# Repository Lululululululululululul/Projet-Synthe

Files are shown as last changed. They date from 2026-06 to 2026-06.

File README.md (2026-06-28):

# MONOSTATION — Firmware

Mini-synthétiseur monophonique numérique à synthèse soustractive.
Projet pluridisciplinaire ISEN2 (2025/2026) — groupe **Synthé**.

**Plateforme :** Teensy 4.1 + Teensy Audio Adapter Board Rev D (codec SGTL5000).

## Membres du groupe

- **Mathieu Gattone** — chef de projet
- **Louis Laurent** — développeur (logiciel / DSP)
- **Doryan Le Coadou** — conception mécanique / CAO, responsable Fablab
- **Lucas Desfougeres** — conception électronique, responsable Fablab

Encadrant : Amaury Auguste — Promotion ISEN2, année 2025/2026.

## Démonstration vidéo

▶️ https://youtu.be/DSE_qQ8myZg

---

## Chaîne de traitement du son

```
OSC1 ┐
     ├─► Mixer ─► Filtre passe-bas résonant ─► Enveloppe ADSR ─► Sortie I²S
OSC2 ┘            (State Variable)
```

Deux oscillateurs (le second désaccordable), un mélangeur, un filtre passe-bas
résonant piloté par deux potentiomètres (coupure + résonance), une enveloppe
ADSR, puis la sortie audio I²S vers le codec.

---

## Organisation du code

Le firmware est découpé en **modules**, suivant la séparation
*interface → logique → traitement du signal* présentée dans le rapport. Chaque
module expose son état et ses fonctions dans un en-tête `.h`, et les implémente
dans le `.cpp` correspondant. Le fichier **commun** `config.h` regroupe tout ce
qui est partagé (brochage, constantes, structures).

| Fichier | Rôle |
|---|---|
| `MONOSTATION.ino` | Point d'entrée : `setup()` et `loop()`. Ne fait qu'orchestrer les modules. |
| `config.h` | **En-tête commun** : brochage Teensy, constantes de réglage, structures `Preset` / `SeqEvent` / `Track`. Que des `#define`, `constexpr` et types — aucune variable d'état. |
| `audio_engine.h` / `.cpp` | **Le son** : chaîne audio Teensy, voix monophonique (pile de notes, priorité à la dernière note), note → fréquence + octave, presets, lecture des potentiomètres vers le filtre. |
| `menu.h` / `.cpp` | **Menu + encodeur** : lecture de l'encodeur rotatif (rotation + clic), machine à états du menu, édition des paramètres (qui délègue le travail sonore au moteur audio). |
| `display.h` / `.cpp` | **Affichage OLED** : barre d'état, menu déroulant et sous-menus. Ne fait que *lire* l'état des autres modules. |
| `sequencer.h` / `.cpp` | **Séquenceur** : enregistrement et relecture de courtes pistes (note on/off horodatés). |

### Comment les modules communiquent

- Chaque variable d'état globale est **définie une seule fois** dans son module
  (état sonore dans `audio_engine.cpp`, état du menu dans `menu.cpp`, état du
  séquenceur dans `sequencer.cpp`) et **déclarée `extern`** dans son en-tête pour
  que les autres modules puissent la lire.
- Le menu ne touche jamais directement aux objets audio : il appelle des
  fonctions du moteur (`audioCycleWaveform`, `audioAdjustEnv`, `audioLoadPreset`…).
- Le séquenceur joue les notes via `audioSeqPlay()` / `audioSeqStop()`.
- L'affichage est purement passif : il lit l'état et le dessine.

---

## Brochage (Teensy 4.1)

| Élément | Broche(s) |
|---|---|
| Encodeur rotatif | CLK = 33, DT = 34, bouton = 35 |
| Clavier do → si | 36, 37, 32, 31, 30, 29, 28 |
| Potentiomètre coupure filtre | A10 |
| Potentiomètre résonance filtre | A11 |
| Écran OLED SSD1306 | I²C (SDA/SCL), adresse `0x3C` |
| Sortie audio | I²S (via l'Audio Adapter Board) |

---

## Dépendances (bibliothèques)

Fournies avec **Teensyduino** (rien à installer) :
- Teensy Audio Library (`Audio.h`)
- `Wire` (I²C), `SPI`
- `Encoder`

À installer via le gestionnaire de bibliothèques de l'IDE Arduino :
- **Adafruit GFX Library**
- **Adafruit SSD1306**
- **Bounce2**

---

## Compilation et téléversement

1. Installer l'**IDE Arduino** puis l'add-on **Teensyduino**.
2. Installer les trois bibliothèques ci-dessus (Croquis → Inclure une
   bibliothèque → Gérer les bibliothèques).
3. Ouvrir `MONOSTATION.ino`. ⚠️ Le **dossier** doit porter le même nom que le
   `.ino` (`MONOSTATION/`) — c'est déjà le cas ici. Les autres fichiers
   (`.h` / `.cpp`) apparaissent alors automatiquement en onglets.
4. Outils → Type de carte → **Teensy 4.1**.
5. Sélectionner le port, puis **Téléverser**.

Le son sort par la prise casque de l'Audio Adapter Board.

---

## Pourquoi des fichiers `.cpp` (C++) et non `.c` (C) ?

Le projet s'appuie sur des **classes C++** : la bibliothèque audio Teensy
(`AudioSynthWaveform`, `AudioFilterStateVariable`…), `Adafruit_SSD1306`,
`Bounce`, `Encoder`. Ces objets n'existent pas en langage C : un fichier `.c`
compilé en C ne pourrait pas les utiliser. Les fichiers d'implémentation sont
donc en `.cpp`. En revanche, le « fichier commun » demandé est bien là : c'est
l'en-tête **`config.h`**, inclus par tous les modules.

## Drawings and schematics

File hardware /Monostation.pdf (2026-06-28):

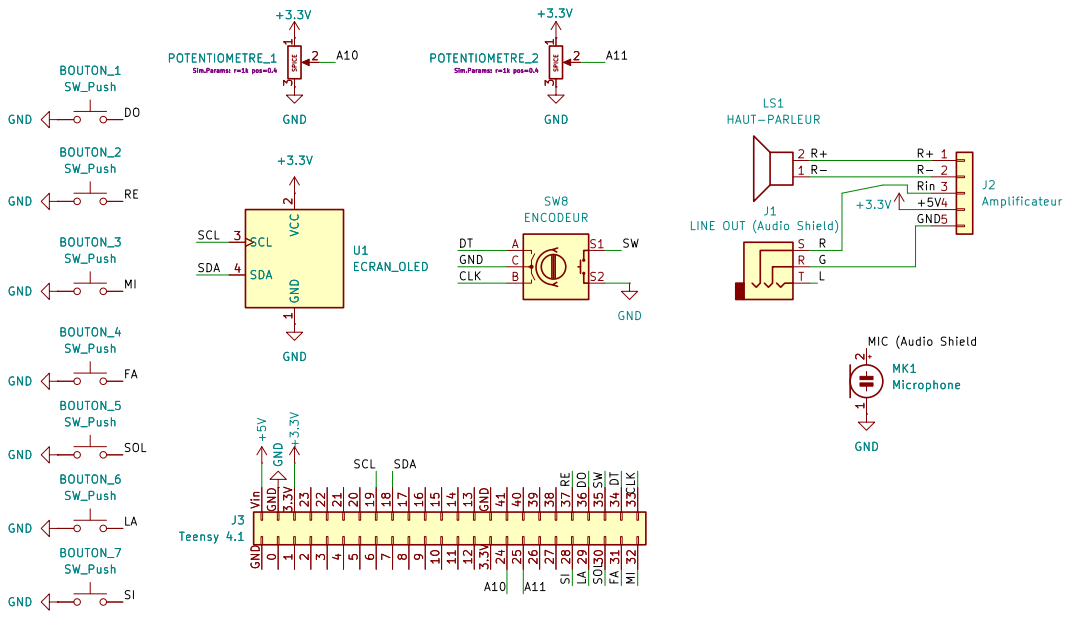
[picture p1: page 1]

3 POTENTIOMETRE_2 BOUTON_1 Sim.Params: r=1k pos=0.4 SW_Push SPICE 1

3 GND MK1 Microphone 1 2 GND GND

LINE OUT (Audio Shield) MI SW

9101112 2322212019181716151413 242526272829303132 414039383736353433 GND Vin GND GND U1
ECRAN_OLED GND
GND

ISEN Méditerranée — Groupe Synthé GND

9101112 2322212019181716151413 242526272829303132 414039383736353433 GND Vin GND GND

Sheet: /
File: Monostation.kicad_sch
Title: MONOSTATION — Schéma électrique

Size: A4 | Rev: 1.0
KiCad E.D.A. 10.0.4 | Id: 1/1

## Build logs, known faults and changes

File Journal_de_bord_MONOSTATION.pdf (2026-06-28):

## Journal de bord — MONOSTATION

Groupe Synthé — Mathieu Gattone, Louis Laurent, Doryan Le Coadou, Lucas Desfougeres Encadrant : Amaury Auguste · Promotion : ISEN2 — 2025/2026
Projet : mini-synthétiseur monophonique numérique (Teensy 4.1 + Audio Adapter Board Rev D)

À propos de ce journal
Ce journal retrace l’avancement du projet sur les cinq semaines. Le suivi est consigné par semaine (réalisations et état d’avancement à chaque jalon). Un point d’équipe hebdomadaire a été tenu pour faire le bilan de l’avancement, identifier les blocages et replanifier si nécessaire.

En continu, sur toute la durée du projet
- Documentation rédigée au fil de l’eau : cahier des charges, état de l’art, protocole de test, puis rapport technique.
- Site web de présentation développé en parallèle (support de la soutenance).
- Dépôt Git partagé dès la première semaine ; journal de bord tenu tout du long.

Semaine 1 — Cadrage et documentation (26/05 → 31/05)
Travail centré sur la documentation : le sujet (grooveboxes / pocket operators) en général, notre instrument en particulier (synthétiseur monophonique à synthèse soustractive), et la plateforme matérielle imposée (Teensy 4.1, Audio Adapter Rev D, Teensy Audio Library). Prise en main de l’environnement Teensyduino et état de l’art des produits comparables.
Jalon 1 (29/05) — Cahier des charges remis. ✔

Semaine 2 — Premiers tests audio (01/06 → 07/06)
Premières soudures de la Teensy et de l’Audio Shield (encore perfectibles — c’était une découverte). Écriture et test de petits programmes pour vérifier que la chaîne audio fonctionne et que du son sort effectivement de la carte.
Jalon 2 (05/06) — Preuve de concept audio. ✔

Semaine 3 — Code et interface sur breadboard (08/06 → 14/06)
Progression sur le firmware : menu simple, clavier de notes (do, ré, mi, fa…) et premiers paramètres exploitables (filtre passe-bas). En parallèle, montage sur breadboard pour installer et tester l’interface : boutons, écran OLED, potentiomètres, ainsi que le haut-parleur — finalement soudé, avec son amplificateur.
Jalon 3 (10/06) — Évaluation d’avancement intermédiaire (notée). ✔

Semaine 4 — Finalisation logicielle et boîtier (15/06 → 21/06)
Code achevé : menu complet et ensemble des fonctions opérationnelles (formes d’onde, filtre, enveloppe ADSR, transposition d’octave…). Démarrage de la fabrication du boîtier et réalisation du schéma électrique sous KiCad.
Jalon 4 (19/06) — Gel des fonctionnalités. ✔

Semaine 5 — Fabrication et rendu (22/06 → 26/06)
Découpe laser du boîtier au Fablab (plusieurs itérations) et nombreuses soudures pour l’assemblage final. Tests de l’instrument, finalisation du rapport et de la vidéo, et répétition de la soutenance.

Jalon 5 (26/06) — Soutenance finale. ✔

Répartition des rôles

Membre | Rôle
Mathieu Gattone | Chef de projet
Louis Laurent | Lead software / DSP
Lucas Desfougeres | Lead électronique · responsable Fablab
Doryan Le Coadou | Lead mécanique / CAO · responsable Fablab

Les rôles ne sont pas étanches : chacun a contribué partout, mais chaque sous-système a un référent responsable.

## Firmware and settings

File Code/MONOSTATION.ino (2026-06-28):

/* =====================================================================
 *  MONOSTATION.ino  —  Point d'entrée du firmware
 * ---------------------------------------------------------------------
 *  Mini-synthétiseur monophonique numérique — Teensy 4.1 + Audio Adapter Rev D
 *  Groupe Synthé — ISEN2 2025/2026
 *
 *  Architecture (séparation interface / logique / DSP) répartie en modules :
 *    config.h          — brochage, constantes, structures communes
 *    audio_engine.*    — LE SON : chaîne DSP, voix monophonique, presets, potards
 *    menu.*            — MENU + ENCODEUR : navigation et édition des paramètres
 *    display.*         — AFFICHAGE OLED : retour visuel
 *    sequencer.*       — SÉQUENCEUR (FS6) : enregistrement / lecture de pistes
 *
 *  Le traitement audio tourne en tâche de fond (moteur audio Teensy / DMA) :
 *  loop() ne fait que lire les entrées, mettre à jour l'état et l'affichage.
 * ===================================================================== */
#include "config.h"
#include "audio_engine.h"
#include "menu.h"
#include "display.h"
#include "sequencer.h"

#include <Audio.h>
#include <Wire.h>

static unsigned long lastDisplay = 0;

// =====================================================================
//  SETUP
// =====================================================================
void setup() {
  Serial.begin(115200);
  AudioMemory(40);     // réserve les blocs mémoire de la chaîne audio
  Wire.begin();        // bus I2C (codec SGTL5000 + écran OLED)

  audioSetup();        // codec, oscillateurs, filtre, enveloppe, entrées de jeu
  displaySetup();      // écran OLED
  menuSetup();         // encodeur + bouton

  audioLoadPreset(presetIndex);  // charge le preset de départ
}

// =====================================================================
//  LOOP
// =====================================================================
void loop() {
  readEncoder();        // rotation de l'encodeur (navigation / édition)
  readMenuButton();     // clic de l'encodeur
  readNotes();          // clavier : pile de notes + déclenchement de la voix
  seqUpdate();          // séquenceur : enregistrement / lecture
  readPots();           // potentiomètres -> filtre (coupure + résonance)

  // Rafraîchissement de l'écran à cadence réduite (~20 img/s)
  if (millis() - lastDisplay > DISPLAY_INTERVAL_MS) {
    drawMenu();
    lastDisplay = millis();
  }
}

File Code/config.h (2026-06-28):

/* =====================================================================
 *  config.h  —  En-tête COMMUN du projet MONOSTATION
 * ---------------------------------------------------------------------
 *  Regroupe tout ce qui est partagé par les autres modules :
 *    - le brochage (broches Teensy 4.1)
 *    - les constantes de réglage (plages, tailles, durées)
 *    - les structures de données communes (Preset, SeqEvent, Track)
 *
 *  Ce fichier ne contient AUCUNE variable d'état ni aucun code : que des
 *  #define, des constantes et des définitions de type. Il peut donc être
 *  inclus sans risque par tous les modules.
 * ===================================================================== */
#ifndef CONFIG_H
#define CONFIG_H

#include <Arduino.h>

// =================== ÉCRAN OLED ===================
constexpr int SCREEN_WIDTH  = 128;
constexpr int SCREEN_HEIGHT = 64;

// =================== BROCHES — ENCODEUR ===================
#define PIN_ENC_CLK 33   // signal A (rotation)
#define PIN_ENC_DT  34   // signal B (rotation)
#define PIN_ENC_SW  35   // bouton-poussoir (clic)

// =================== BROCHES — CLAVIER (do … si) ===================
#define BTN_DO  36
#define BTN_RE  37
#define BTN_MI  32
#define BTN_FA  31
#define BTN_SOL 30
#define BTN_LA  29
#define BTN_SI  28

// =================== BROCHES — POTENTIOMÈTRES ===================
#define POT_FREQ A10   // coupure du filtre (cutoff)
#define POT_AMP  A11   // résonance du filtre

// =================== PLAGES DU FILTRE ===================
constexpr float CUTOFF_MIN = 80.0f;    // Hz
constexpr float CUTOFF_MAX = 9000.0f;  // Hz
constexpr float RESO_MIN   = 0.7f;
constexpr float RESO_MAX   = 4.5f;

// =================== OSCILLATEURS ===================
constexpr int   NUM_WAVES = 4;     // sinus, dent de scie, carré, triangle
constexpr float OSC_AMP   = 0.8f;  // amplitude de chaque oscillateur

// =================== ANTI-REBOND (boutons) ===================
constexpr unsigned long DEBOUNCE_MS = 8;

// =================== ENCODEUR ===================
constexpr int STEPS_PER_DETENT = 4; // pas codeur par cran physique

// =================== RAFRAÎCHISSEMENT OLED ===================
constexpr int DISPLAY_INTERVAL_MS = 50; // ~20 images/s

// =================== CLAVIER ===================
constexpr int NUM_KEYS = 7;
// Fréquences (Hz) des notes do … si, octave de référence
constexpr float FREQ_DO  = 261.63f;
constexpr float FREQ_RE  = 293.66f;
constexpr float FREQ_MI  = 329.63f;
constexpr float FREQ_FA  = 349.23f;
constexpr float FREQ_SOL = 392.00f;
constexpr float FREQ_LA  = 440.00f;
constexpr float FREQ_SI  = 493.88f;

// =================== MENU — index des entrées ===================
#define IDX_PRESET  0
#define IDX_OSC     1
#define IDX_DETUNE  2
#define IDX_FILTER  3
#define IDX_ENV     4
#define IDX_OCTAVE  5
#define IDX_VOLUME  6
#define IDX_SEQ     7
constexpr int MENU_SIZE = 8;

// =================== PRESETS ===================
constexpr int NUM_PRESETS = 6;

// =================== SÉQUENCEUR (FS6) ===================
constexpr int      MAX_TRACKS   = 4;
constexpr int      MAX_EVENTS   = 64;
constexpr uint32_t TRACK_LEN_MS = 3000; // durée d'une piste (ms)

// =====================================================================
//  STRUCTURES DE DONNÉES COMMUNES
// =====================================================================

// Un preset = un jeu complet de paramètres sonores rappelable (FS4).
struct Preset {
  const char* name;
  int   wave;        // index de forme d'onde
  int   octave;      // décalage d'octave
  float a, d, s, r;  // enveloppe ADSR (A, D en ms ; S 0..1 ; R en ms)
  float det, mix;    // désaccord (cents) et niveau de l'OSC2
  float cutoffRef;   // coupure indicative (affichage)
  float resoRef;     // résonance indicative (affichage)
};

// Un événement du séquenceur = un note on/off horodaté.
struct SeqEvent {
  uint16_t t;     // instant depuis le début de la piste (ms)
  bool     on;    // true = note on, false = note off
  int8_t   key;   // touche concernée (-1 si silence)
  float    freq;  // fréquence à jouer
};

// Une piste = une suite d'événements enregistrés.
struct Track {
  SeqEvent ev[MAX_EVENTS];
  int      count;
  bool     used;
};

#endif // CONFIG_H
